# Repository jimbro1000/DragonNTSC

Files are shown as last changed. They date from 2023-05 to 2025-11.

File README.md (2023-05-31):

# NTSC VIDEO BOARD FOR DRAGON 32 RECREATION Rev 3 #

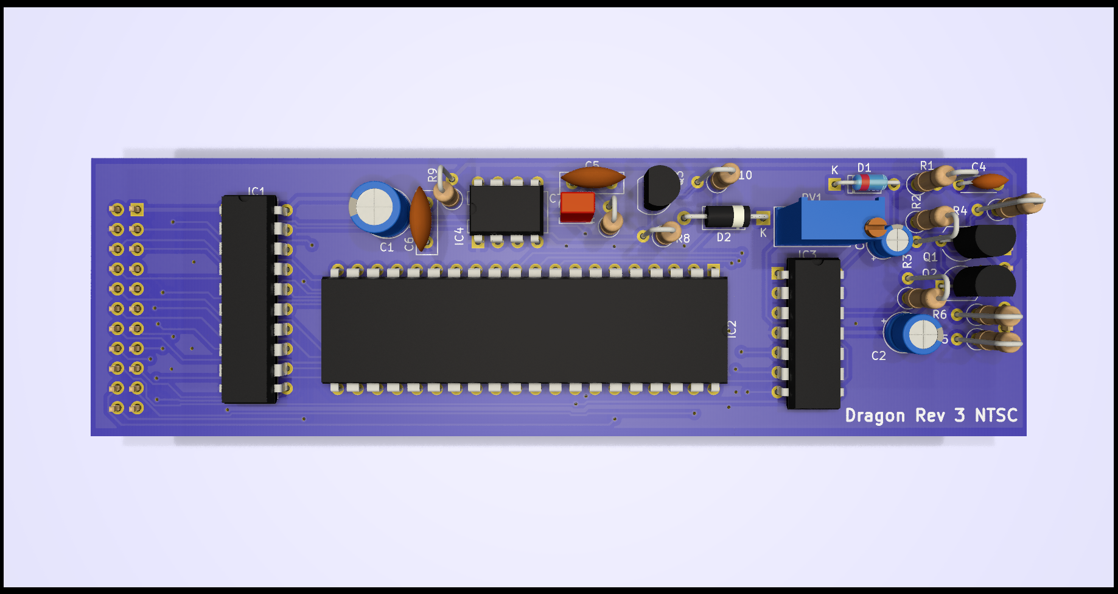
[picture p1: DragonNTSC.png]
render of NTSC video board


To further improve video quality on the Dragon 32 this
board completely isolates the video circuits from the rest
of the Dragon by making it a plugin. This also means that
only a single version of the Dragon rev 3 board is needed to
provide a PAL or NTSC solution.

## Progress ##

This is a complete first hack at the design, based on the
reference design in the 6847 datasheet with supporting
information from the MC1372 datasheet.

The generator and amplifier circuits are isolated and
*should* be good for a clean video signal.

## Note ##

Given most modern TVs work with NTSC **and** PAL, switching
automatically, this slimline video board (compared to the PAL
version of the board) should be a cheaper and more attractive
option. The component count is *much* lower and the harder to
find analogue multiplexer is not needed.

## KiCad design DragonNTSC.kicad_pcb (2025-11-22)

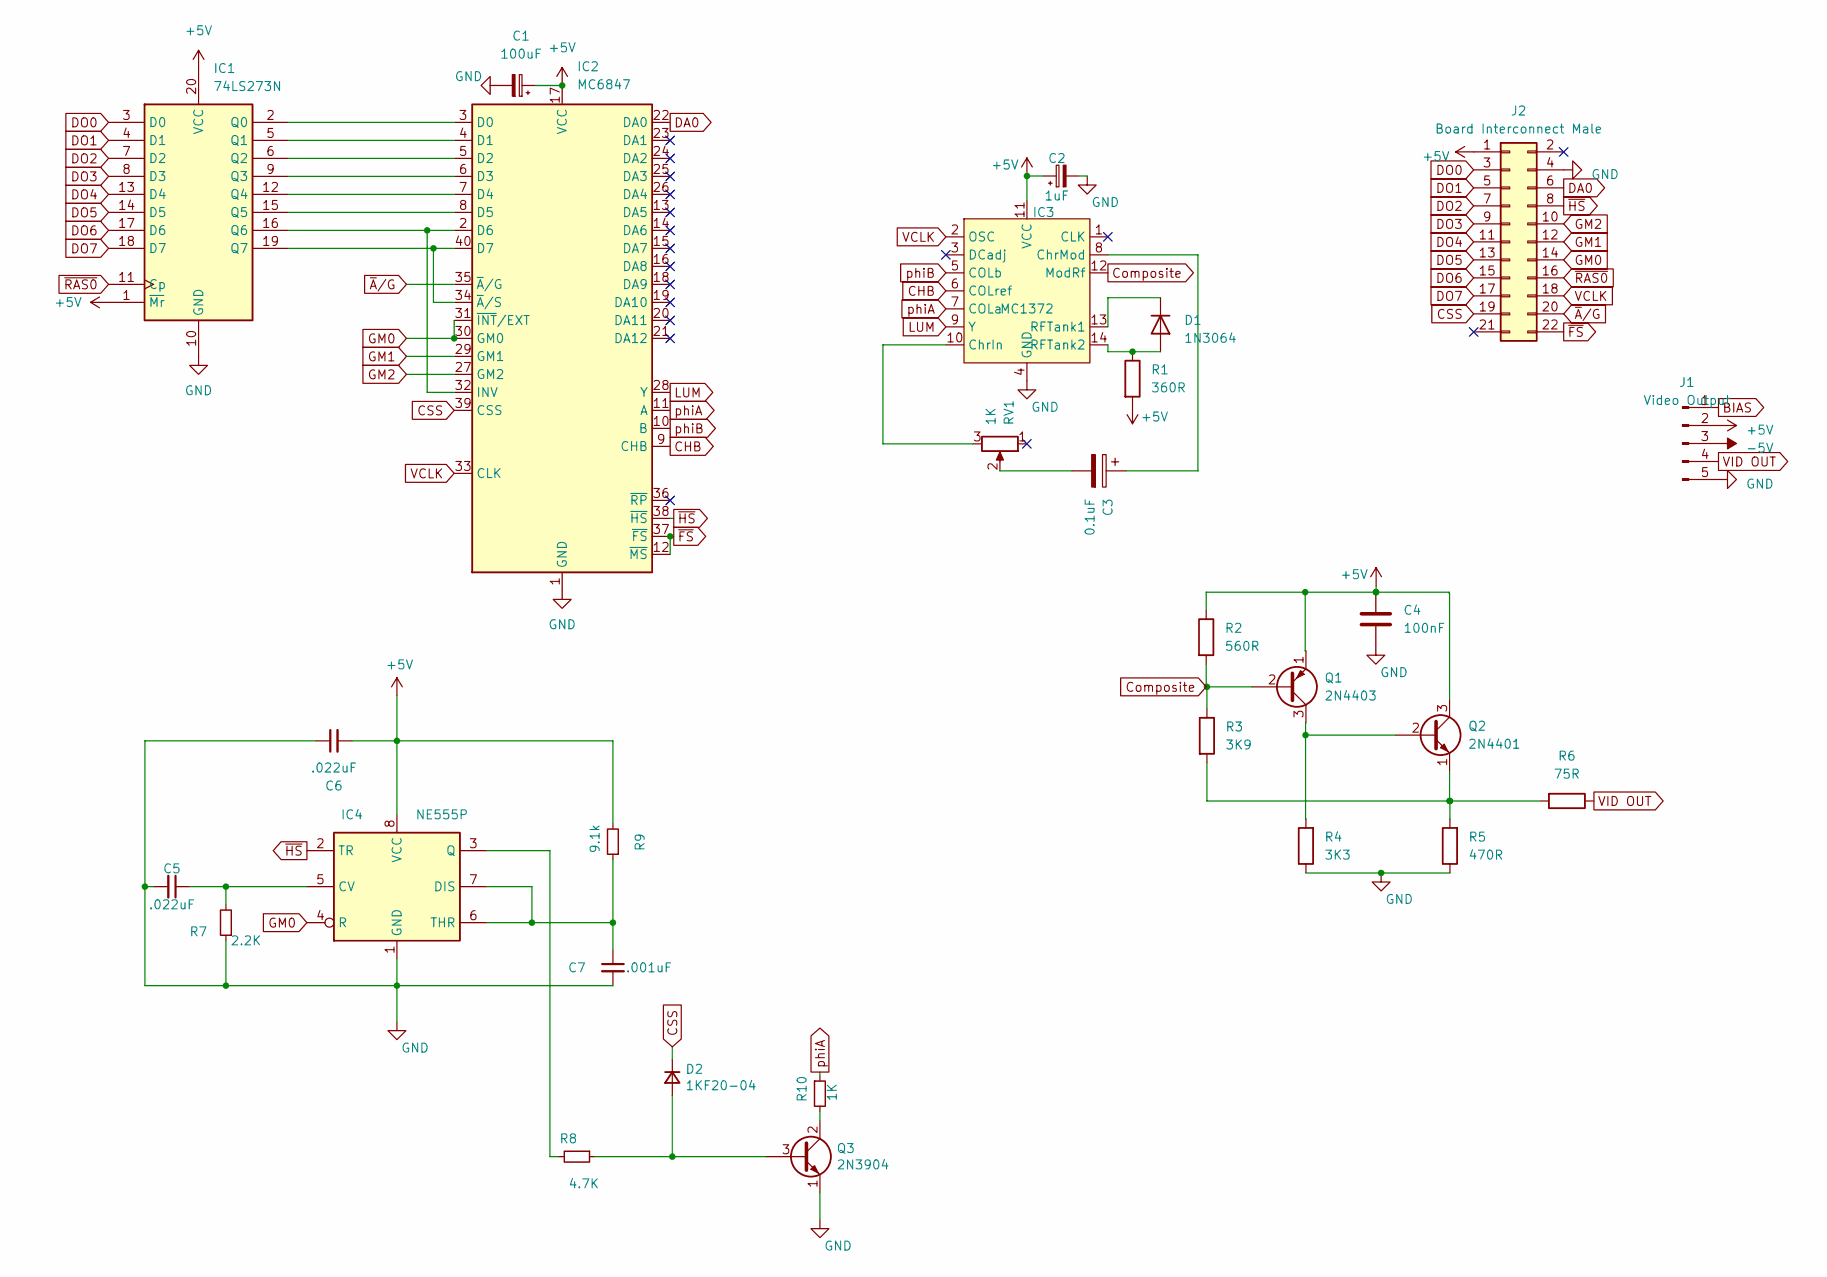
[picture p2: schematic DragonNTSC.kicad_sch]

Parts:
C1: 100uF; CP_Radial_D6.3mm_P2.50mm; DigiKey 732-8598-1-ND
C2: 1uF; CP_Radial_D5.0mm_P2.50mm; DigiKey 478-8984-1-ND
C3: 0.1uF; CP_Radial_D4.0mm_P2.00mm
C4: 100nF; C_Disc_D4.3mm_W1.9mm_P5.00mm
C5, C6: .022uF; C_Disc_D8.0mm_W2.5mm_P5.00mm; Manufacturer part# C317C223M5U5TA7301
C7: .001uF; C_Rect_L4.0mm_W2.5mm_P2.50mm; Manufacturer part# C315C102K1R5TA7301
D1: 1N3064; D_DO-35_SOD27_P7.62mm_Horizontal
D2: 1KF20-04; D_A-405_P10.16mm_Horizontal; Manufacturer part# 1N4148
IC1: 74LS273N; DIP-20_W7.62mm; DigiKey 296-1657-5-ND
IC2: MC6847; DIP-40_W15.24mm
IC3: MC1372; DIP-14_W7.62mm
IC4: NE555P; DIP-8_W7.62mm; Manufacturer part# A 08-LC-TT
J1: Video Output; PinHeader_1x05_P2.54mm_Vertical
J2: Board Interconnect Male; PinHeader_2x11_P2.54mm_Vertical
Q1: 2N4403; TO-92_Inline_Wide
Q2: 2N4401; TO-92_Inline_Wide
Q3: 2N3904; TO-92_Inline; Manufacturer part# PN2222A PBFREE
R1: 360R; R_Axial_DIN0207_L6.3mm_D2.5mm_P2.54mm_Vertical
R2: 560R; R_Axial_DIN0207_L6.3mm_D2.5mm_P2.54mm_Vertical
R3: 3K9; R_Axial_DIN0207_L6.3mm_D2.5mm_P2.54mm_Vertical
R4: 3K3; R_Axial_DIN0207_L6.3mm_D2.5mm_P2.54mm_Vertical
R5: 470R; R_Axial_DIN0207_L6.3mm_D2.5mm_P2.54mm_Vertical
R6: 75R; R_Axial_DIN0207_L6.3mm_D2.5mm_P2.54mm_Vertical
R7: 2.2K; R_Axial_DIN0207_L6.3mm_D2.5mm_P2.54mm_Vertical; Manufacturer part# MFR-25FRF52-2K2
R8: 4.7K; R_Axial_DIN0207_L6.3mm_D2.5mm_P2.54mm_Vertical; Manufacturer part# Stackpole Electronics Inc
R9: 9.1k; R_Axial_DIN0207_L6.3mm_D2.5mm_P2.54mm_Vertical; Manufacturer part# CF14JT9K10
R10: 1K; R_Axial_DIN0207_L6.3mm_D2.5mm_P2.54mm_Vertical; Manufacturer part# CF14JT1K00
RV1: 1K; Potentiometer_Bourns_3296W_Vertical

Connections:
+5V: C1.1, C2.1, C4.1, C6.2, IC1.1 (~Mr), IC1.20 (VCC), IC2.17 (VCC), IC3.11 (VCC), IC4.8 (VCC), J1.2, J2.1, Q1.1 (E), Q2.3 (C), R1.2, R2.1, R9.2
-5V: J1.3
BIAS: J1.1
CHB: IC2.9 (CHB), IC3.6 (COLref)
CSS: D2.1 (K), IC2.39 (CSS), J2.19
Composite: IC3.12 (ModRf), Q1.2 (B), R2.2, R3.1
DA0: IC2.22 (DA0), J2.6
DO0: IC1.3 (D0), J2.3
DO1: IC1.4 (D1), J2.5
DO2: IC1.7 (D2), J2.7
DO3: IC1.8 (D3), J2.9
DO4: IC1.13 (D4), J2.11
DO5: IC1.14 (D5), J2.13
DO6: IC1.17 (D6), J2.15
DO7: IC1.18 (D7), J2.17
GM0: IC2.30 (GM0), IC2.31 (~INT/EXT), IC4.4 (R), J2.14
GM1: IC2.29 (GM1), J2.12
GM2: IC2.27 (GM2), J2.10
GND: C1.2, C2.2, C4.2, C5.2, C6.1, C7.2, IC1.10 (GND), IC2.1 (GND), IC3.4 (GND), IC4.1 (GND), J1.5, J2.4, Q3.1 (E), R4.1, R5.1, R7.1
LUM: IC2.28 (Y), IC3.9 (Y)
unnamed: C3.2, RV1.2
unnamed: D1.2 (A), IC3.14 (RFTank2), R1.1
unnamed: D1.1 (K), IC3.13 (RFTank1)
unnamed: D2.2 (A), Q3.3 (B), R8.1
unnamed: IC1.2 (Q0), IC2.3 (D0)
unnamed: IC1.5 (Q1), IC2.4 (D1)
unnamed: IC1.6 (Q2), IC2.5 (D2)
unnamed: IC1.9 (Q3), IC2.6 (D3)
unnamed: IC1.12 (Q4), IC2.7 (D4)
unnamed: IC1.15 (Q5), IC2.8 (D5)
unnamed: IC1.16 (Q6), IC2.2 (D6), IC2.32 (INV)
unnamed: IC1.19 (Q7), IC2.34 (~A/S), IC2.40 (D7)
unnamed: IC3.10 (ChrIn), RV1.3
unnamed: C3.1, IC3.8 (ChrMod)
unnamed: C5.1, IC4.5 (CV), R7.2
unnamed: C7.1, IC4.6 (THR), IC4.7 (DIS), R9.1
unnamed: IC4.3 (Q), R8.2
unnamed: Q1.3 (C), Q2.2 (B), R4.2
unnamed: Q2.1 (E), R3.2, R5.2, R6.2
unnamed: Q3.2 (C), R10.2
VCLK: IC2.33 (CLK), IC3.2 (OSC), J2.18
VID OUT: J1.4, R6.1
phiA: IC2.11 (A), IC3.7 (COLa), R10.1
phiB: IC2.10 (B), IC3.5 (COLb)
~A/G: IC2.35 (~A/G), J2.20
~FS: IC2.12 (~MS), IC2.37 (~FS), J2.22
~HS: IC2.38 (~HS), IC4.2 (TR), J2.8
~RAS0: IC1.11 (Cp), J2.16

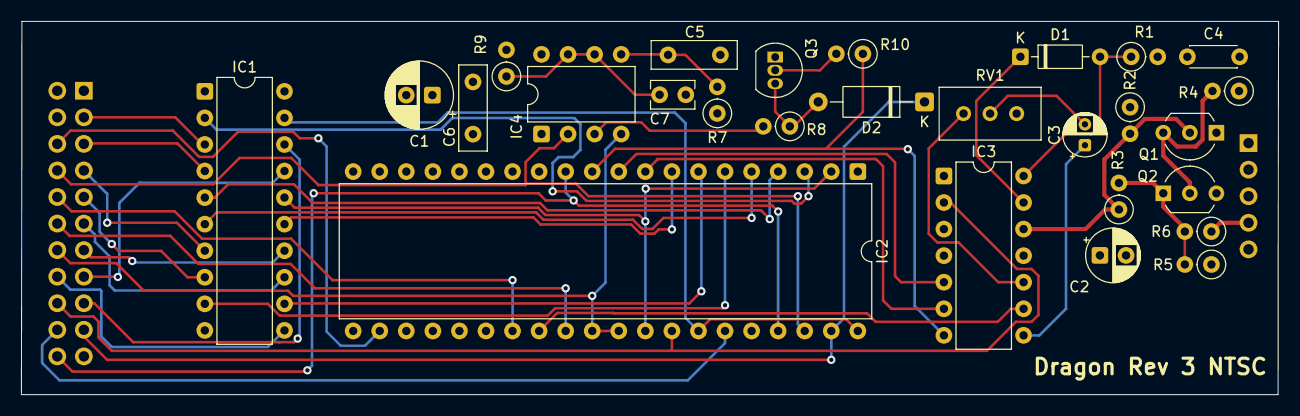
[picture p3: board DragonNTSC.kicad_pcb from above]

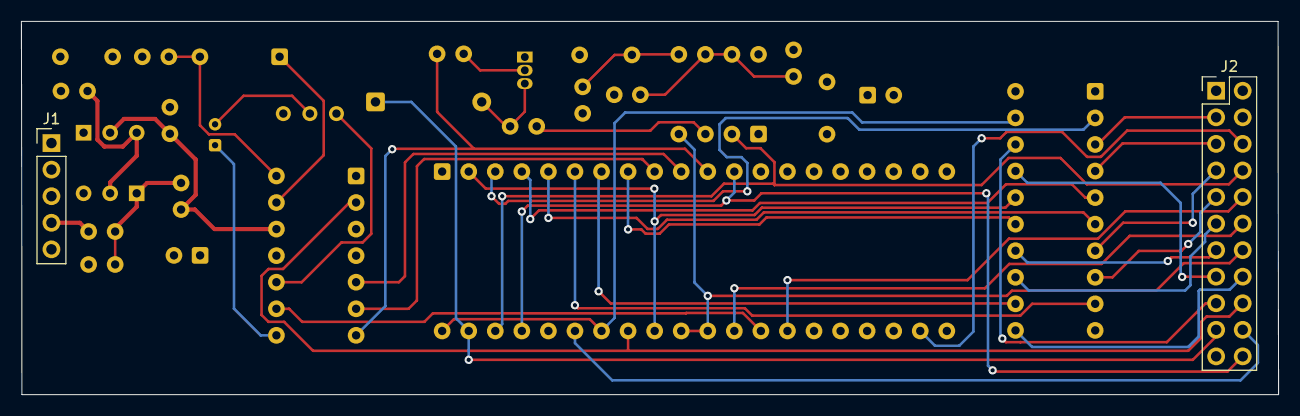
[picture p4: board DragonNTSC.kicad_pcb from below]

Board: 4 copper layers, 120.2 x 35.7 mm, 29 parts (2 on the bottom side), 46 nets.

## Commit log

2023-06-01 add missing css and fs lines
    [DragonNTSC.kicad_pcb, DragonNTSC.kicad_sch]
2024-03-02 add 555 timer
    [DragonNTSC.kicad_pcb, DragonNTSC.kicad_sch]
2025-11-22 migrate to kicad 9
    [DragonNTSC.kicad_pcb, DragonNTSC.kicad_sch]
2025-11-22 revise for fab
    [DragonNTSC.kicad_pcb, DragonNTSC.kicad_sch]
